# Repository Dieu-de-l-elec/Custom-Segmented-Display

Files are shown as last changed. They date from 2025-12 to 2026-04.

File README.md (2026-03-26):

# Custom Segmented Display

This project is a customizable Segmented display, consisting of a PCB and a top 3d printed diffuser part.
It comes with 32 0603 LEDs arranged in 3 digits, 5-LED light bar and 4 custom indicators. For the top cover, it's mainly a 3d printed part, with tracing paper acting as a diffuser. I'm using double sided adhesive sheets to place the diffusing film on top of the 3d print. The top cover can be attached to the PCB with 4 Phillips head screws. (4 threaded inserts would have been added to the 3d printed part beforehand).

demo here: https://youtu.be/plXIUfEDHeE

banner
RENDER CAD 2
RENDER CAD 2

# Key features:
- **32 LEDs**
- **3 digits** (7 segment digit) including two dots
- 5-LED bar on the bottom left corner
- based on **2 AW9523** ICs: cheap and efficient
- **I²C** communication: up to 2 modules on the same I²C bus
- each LED is driven in **constant current**, with **256 levels of brightness**
- The top diffuser 3d printed part can be swapped with a custom made diffuser, so multiple segmented displays fonts can be achieved. Here is a link of an awesome video made by Pozy, exploring custom Segmented Display fonts: *Segmented Displays* link: https://www.youtube.com/watch?v=RTB5XhjbgZA&t=301s. I designed a top cover taking inspiration from the ***Seamless*** font (4:35)
- Pins accessibles via **Dupont Headers** or **FPC 6P**
- PCB size: 80mm by 25mm
  
# Pinout:

- ***GND***
- ***N.RST*** (negative Reset) Pull LOW to reset the two AW9523 ICs
- ***N.EN*** (negative LED enable) Pull LOW to enable VCC.LED: Only when the AW9523 are well initialized.
- ***SCL***
- ***SDA***
- ***VCC*** 5.0V or 3.3V: 3.3V only possible if the 0603 LEDs used have a forward voltage low enough (if powered with 3.3V, prefer using RED LEDs)

# Software

I made an Arduino code, which while not being the most optimized one, should be sufficient for testing...

# PCB design:

2 Layer PCB designed in EASYEDA (Pro edition)

# Schematic:

SCHEMATIC

# PCB Layout: 

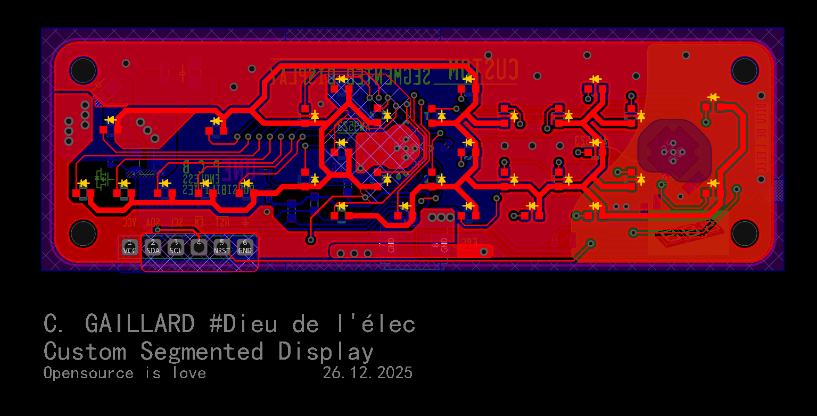
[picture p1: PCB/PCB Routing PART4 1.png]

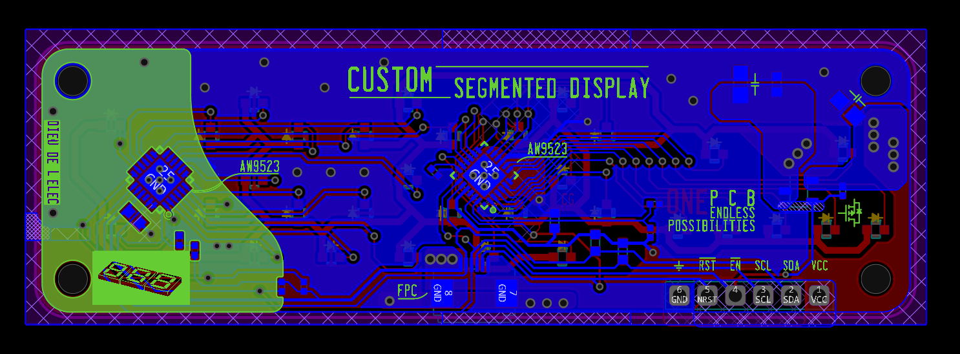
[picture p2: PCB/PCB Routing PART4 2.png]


# CAD (Top cover diffuser):

RENDER CAD 2
RENDER CAD 1

# Renders:
PCB Routing Part3 iso
RENDER 1B
RENDER 1
RENDER 2
RENDER 3
RENDER 4
RENDER 5
RENDER 6
RENDER CAD 1
RENDER CAD 2
RENDER CAD 3
RENDER CAD 4
RENDER CAD 5
RENDER CAD 7
RENDER CAD 6

# Building the display:

Here are the PCB soldered:




## Top diffuser:
The parts are 3d printed in a black filament, so that light cannot pass through, resulting in sharp segments.
The 4 tiles didn't came out perfect, the 3d printed walls almost fused together so the icons aren't really visible, maybe in a V2 I'll increase the groove size.
Other than that, the 3d printed top cover was looking really good, and after sanding down the two top and bottom surfaces, adding the 4 threaded inserts, and placing tracing paper on top with the help of double sided translucent adhesive, the top diffuser was ready to go. Here is the result:












# BOM:

Qty	| Part	| Value | link
--- | --- | --- | ---
3	| 0603 Ceramic Cap	| 100nF | https://www.lcsc.com/product-detail/C66501.html
2	| 0805 Ceramic Cap	| 22µF | https://www.lcsc.com/product-detail/C602037.html
1	| FPC 6P Connector	| FPC-05F-6PH20 | https://www.lcsc.com/product-detail/C2856796.html
1	| Dupont Header 1x6P	| HDR-M_2.54_1x6P | https://www.lcsc.com/product-detail/C37208.html
32 | 0603 LEDs	| Any color | https://www.lcsc.com/product-detail/C965800.html
1	| P-channel Mosfet	| AO3415A | https://www.lcsc.com/product-detail/C133233.html?s_z=n_AO3415A
6	| 0402 Resistor	| 1K | https://www.lcsc.com/product-detail/C2906864.html
2	| 0402 Resistor	| 10K | https://www.lcsc.com/product-detail/C2906861.html
2	| 0603 Resistor	| 4.7K | https://www.lcsc.com/product-detail/C2907034.html
2	| QFN-24 16 channel LED Controller | AW9523BTQR | https://www.lcsc.com/product-detail/C148077.html
1	| Custom PCB | 	
_ | _ | _ | _
_ | _ | _ | _
4	| Threaded inserts	| M2x4x3.5 | https://fr.aliexpress.com/item/1005010298290044.html
4	| Screws	| M2x5 | https://fr.aliexpress.com/item/1005005395957622.html
1	| Custom 3D printed Top Cover Diffuser	| _
(1)	| Double sided adhesive sheet	| (diffusing top layer) | https://fr.aliexpress.com/item/1005005445296074.html
(1)	| Tracing paper sheet	| (diffusing top layer) | https://fr.aliexpress.com/item/1005007419166941.html
(1)	| FPC ribbon cable	8P | .5mm pitch .300mm thick | https://www.lcsc.com/product-detail/C2857689.html

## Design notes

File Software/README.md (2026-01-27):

Here are the Arduino codes for testing the Custom segmented display

The 'Custom_Segmented_Display_demo_code.ino' file is only kept here for archive.

The recommended demo code is now : 'DEMO_Custom_Segmented_Display.ino'

code explanation

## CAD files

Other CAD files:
CAD and RENDERS/CUSTOM SEGMENTED DISPLAY 3D PCB.f3d
CAD and RENDERS/Custom SEGMENTED DISPLAY ASSEMBLY.f3z

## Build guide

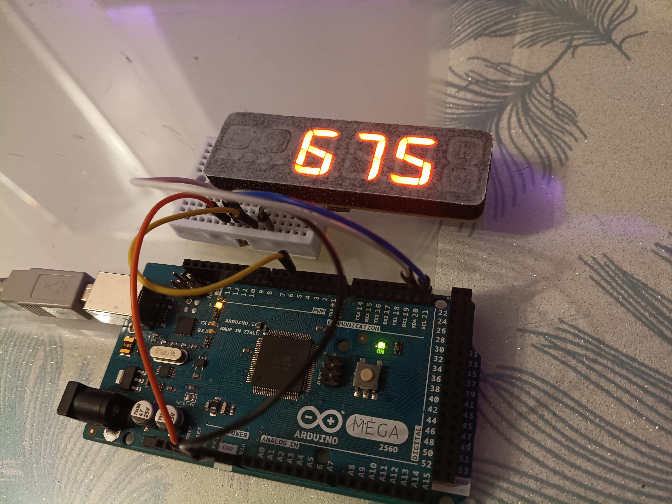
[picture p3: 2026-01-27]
Build Imgs/Build 07.jpg

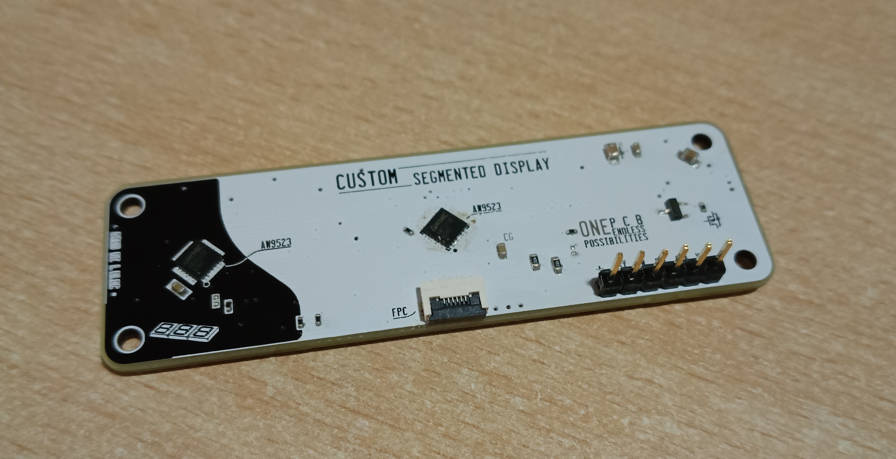
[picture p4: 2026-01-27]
Build Imgs/Build 001.jpg

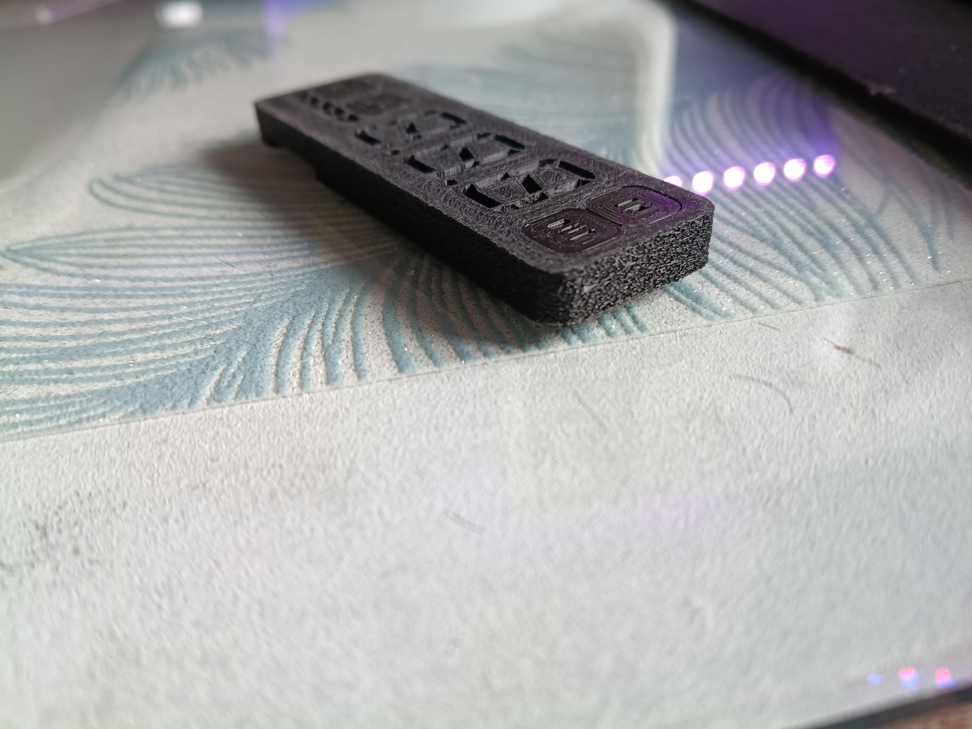
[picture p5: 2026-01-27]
Build Imgs/Build 08.jpg

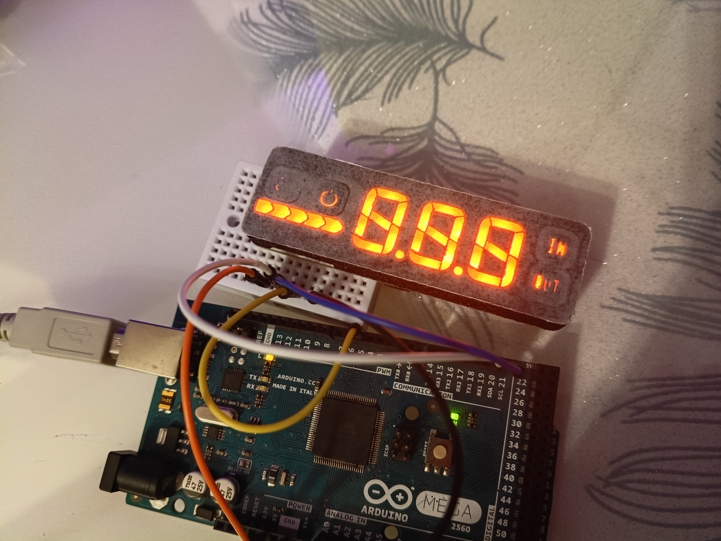
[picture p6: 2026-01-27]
Build Imgs/Build 06.jpg

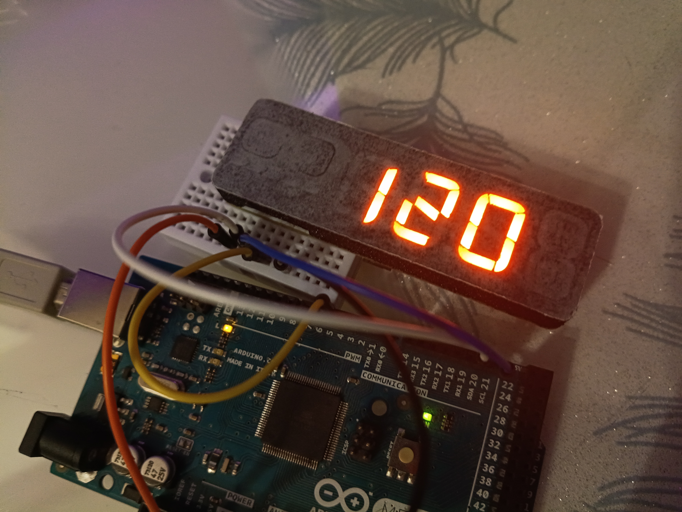
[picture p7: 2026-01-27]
Build Imgs/Build 04.jpg

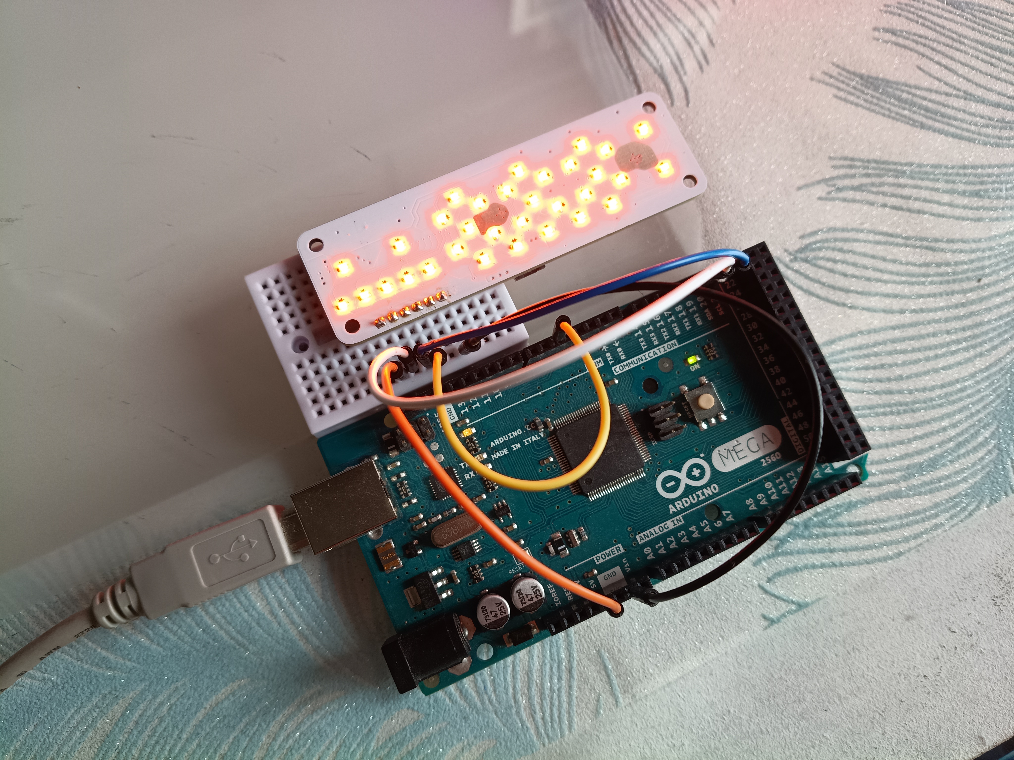
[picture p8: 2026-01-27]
Build Imgs/Build 10.jpg

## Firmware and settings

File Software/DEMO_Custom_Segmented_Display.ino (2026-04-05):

// Custom 7 segment Display Code based on the Adafruit AW9523 library example 
// Newer version, this is far from the most optimized code, but at least it's more efficient than the previous code. It's still good enough for my use cases.

#include "Adafruit_AW9523.h"

Adafruit_AW9523 awA;
Adafruit_AW9523 awB;

int brightness = 80;         // 0 to 255        255 = IMAX, should be 37mA [...]

#define LED_Neg_EN 5 //replace with whatever pin you want
#define Neg_RST 6    // here too

uint8_t pinsMatrixA [4][4] = {
  {0, 1, 2, 3},         //  C_2 [0][0]       C_3 [0][1]    E_3 [0][2]     G_3 [0][3]
  {4, 5, 6, 7},         //  G_2 [1][0]       F_3 [1][1]    B_2 [1][2]     F_2 [1][3]
  {8, 9, 10, 11},       //  ICON4 [2][0]     D_3 [2][1]    DP_2 [2][2]    D_2 [2][3]
  {12, 13, 14, 15}      //  A_2 [3][0]       A_3 [3][1]    B_3 [3][2]     ICON3 [3][3]
};

uint8_t pinsMatrixB [4][4] = {
  {0, 1, 2, 3},         //  LED_BAR_2 [0][0]    LED_BAR_1 [0][1]      ICON1 [0][2]        ICON3 [0][3]
  {4, 5, 6, 7},         //  A_1 [1][0]          F_1 [1][1]            B_1 [1][2]          G_1 [1][3]
  {8, 9, 10, 11},       //  E_1 [2][0]          LED_BAR_5 [2][1]      LED_BAR_4 [2][2]    LED_BAR_3 [2][3]
  {12, 13, 14, 15}      //  C_1 [3][0]          D_1 [3][1]            DP_1 [3][2]         E_2 [3][3]
};

bool stateMatrixA [4][4] = {
  {0, 0, 0, 0},         //  C_2 [0][0]       C_3 [0][1]    E_3 [0][2]     G_3 [0][3]
  {0, 0, 0, 0},         //  G_2 [1][0]       F_3 [1][1]    A_2 [1][2]     F_2 [1][3]
  {0, 0, 0, 0},         //  ICON4 [2][0]    D_3 [2][1]    DP3 [2][2]    D_2 [2][3]
  {0, 0, 0, 0}         //  A_2 [3][0]       A_3 [3][1]    B_3 [3][2]     ICON3 [3][3]
};

bool NstateMatrixA [4][4] = {
  {0, 0, 0, 0},         //  C_2 [0][0]       C_3 [0][1]    E_3 [0][2]     G_3 [0][3]
  {0, 0, 0, 0},         //  G_2 [1][0]       F_3 [1][1]    A_2 [1][2]     F_2 [1][3]
  {0, 0, 0, 0},         //  ICON4 [2][0]    D_3 [2][1]    DP3 [2][2]    D_2 [2][3]
  {0, 0, 0, 0}         //  A_2 [3][0]       A_3 [3][1]    B_3 [3][2]     ICON3 [3][3]
};

bool stateMatrixB [4][4] = {
  {0, 0, 0, 0},         //  LED_BAR_2 [0][0]    LED_BAR_1 [0][1]      ICON1 [0][2]        ICON2 [0][3]
  {0, 0, 0, 0},         //  A_1 [1][0]          F_1 [1][1]            B_1 [1][2]          G_1 [1][3]
  {0, 0, 0, 0},         //  E_1 [2][0]          LED_BAR_5 [2][1]      LED_BAR_4 [2][2]    LED_BAR_3 [2][3]
  {0, 0, 0, 0}         //  C_1 [3][0]          D_1 [3][1]            DP_1 [3][2]         E_2 [3][3]
};

bool NstateMatrixB [4][4] = {
  {0, 0, 0, 0},         //  LED_BAR_2 [0][0]    LED_BAR_1 [0][1]      ICON1 [0][2]        ICON2 [0][3]
  {0, 0, 0, 0},         //  A_1 [1][0]          F_1 [1][1]            B_1 [1][2]          G_1 [1][3]
  {0, 0, 0, 0},         //  E_1 [2][0]          LED_BAR_5 [2][1]      LED_BAR_4 [2][2]    LED_BAR_3 [2][3]
  {0, 0, 0, 0}         //  C_1 [3][0]          D_1 [3][1]            DP_1 [3][2]         E_2 [3][3]
};


void setup() {
  pinMode (LED_Neg_EN, OUTPUT);
  digitalWrite (LED_Neg_EN, HIGH);
  Serial.begin(115200);
  while (!Serial) delay(1);  // wait for serial port to open

  Serial.println("Custom Segmented Display ready to use");

  if (! awA.begin(0x5B)) { // or 0x59
    Serial.println("AW9523-A not found...");
    while (1) delay(10);  // halt forever
  }

  if (! awB.begin(0x58)) { // or 0x5B
    Serial.println("AW9523-B not found...");
    while (1) delay(10);  // halt forever
  }

  Serial.println("Custom Segmented display ready to go!");

  for (int PIN = 0; PIN <= 15; PIN++) {
    awA.pinMode(PIN, AW9523_LED_MODE); // set to constant current drive
    awB.pinMode(PIN, AW9523_LED_MODE); // set to constant current drive
  }
  delay (2000);
  digitalWrite (LED_Neg_EN, LOW);     // Enable VCC.LEDs

}

void loop() {
  clearALL();
  for (int b = 0; b <= 100; b++) {    // two dots gradually lighting up
    brightness = b;
    NstateMatrixB[3][2] = 1;    // DP_1
    NstateMatrixA[2][2] = 1;    // DP_2
    forcedRefreshDisplay();
    delay (100);
  }
  clearALL();
  for (int level = 0; level <= 5; level++) {    // light Bar test
    LightBar (level);
    delay (1000);
  }

  for (int b = 0; b <= 80; b++) {
    brightness = b;
    litALL();
    forcedRefreshDisplay();
    delay (100);
  }
  clearALL();
  NstateMatrixB[0][2] = 1;    // Icon 1
  delay (800);
  refreshDisplay();
  NstateMatrixB[0][3] = 1;    // Icon 2
  delay (800);
  refreshDisplay();
  NstateMatrixA[3][3] = 1;    // Icon 3
  delay (800);
  refreshDisplay();
  NstateMatrixA[2][0] = 1;    // Icon 4
  delay (800);
  refreshDisplay();
  delay (2000);
  clearALL();

  for (int num = 0; num <= 999; num++) {    // counts up to 999
    displayNumber (num);
    delay (150);
  }
  clearALL();
}

void displayDIGIT (int number, int digit) {
  
  bool  A_1 = NstateMatrixB[1][0];
  bool  A_2 = NstateMatrixA[3][0];
  bool  A_3 = NstateMatrixA[3][1];

  bool B_1 = NstateMatrixB[1][2];
  bool B_2 = NstateMatrixA[1][2];
  bool B_3 = NstateMatrixA[3][2];

  bool C_1 = NstateMatrixB[3][0];
  bool C_2 = NstateMatrixA[0][0];
  bool C_3 = NstateMatrixA[0][1];

  bool D_1 = NstateMatrixB[3][1];
  bool D_2 = NstateMatrixA[2][3];
  bool D_3 = NstateMatrixA[2][1];

  bool E_1 = NstateMatrixB[2][0];
  bool E_2 = NstateMatrixB[3][3];
  bool E_3 = NstateMatrixA[0][2];

  bool F_1 = NstateMatrixB[1][1];
  bool F_2 = NstateMatrixA[1][3];
  bool F_3 = NstateMatrixA[1][1];

  bool G_1 = NstateMatrixB[1][3];
  bool G_2 = NstateMatrixA[1][0];
  bool G_3 = NstateMatrixA[0][3];

  bool DP_1 = NstateMatrixB[3][2];
  bool DP_2 = NstateMatrixA[2][2];

  switch (digit) {
    case 1 :
      switch (number) {
        case 0:
          A_1 = 1;
          B_1 = 1;
          C_1 = 1;
          D_1 = 1;
          E_1 = 1;
          F_1 = 1;
          G_1 = 0;
          break;
        case 1:
          A_1 = 0;
          B_1 = 1;
          C_1 = 1;
          D_1 = 0;
          E_1 = 0;
          F_1 = 0;
          G_1 = 0;
          break;
        case 2:
          A_1 = 1;
          B_1 = 1;
          C_1 = 0;
          D_1 = 1;
          E_1 = 1;
          F_1 = 0;
          G_1 = 1;
          break;
        case 3:
          A_1 = 1;
          B_1 = 1;
          C_1 = 1;
          D_1 = 1;
          E_1 = 0;
          F_1 = 0;
          G_1 = 1;
          break;
        case 4:
          A_1 = 0;
          B_1 = 1;
          C_1 = 1;
          D_1 = 0;
          E_1 = 0;
          F_1 = 1;
          G_1 = 1;
          break;
        case 5:
          A_1 = 1;
          B_1 = 0;
          C_1 = 1;
          D_1 = 1;
          E_1 = 0;
          F_1 = 1;
          G_1 = 1;
          break;
        case 6:
          A_1 = 1;
          B_1 = 0;
          C_1 = 1;
          D_1 = 1;
          E_1 = 1;
          F_1 = 1;
          G_1 = 1;
          break;
        case 7:
          A_1 = 1;
          B_1 = 1;
          C_1 = 1;
          D_1 = 0;
          E_1 = 0;
          F_1 = 0;
          G_1 = 0;
          break;
        case 8:
          A_1 = 1;
          B_1 = 1;
          C_1 = 1;
          D_1 = 1;
          E_1 = 1;
          F_1 = 1;
          G_1 = 1;
          break;
        case 9:
          A_1 = 1;
          B_1 = 1;
          C_1 = 1;
          D_1 = 1;
          E_1 = 0;
          F_1 = 1;
          G_1 = 1;
          break;
      }
      break;

    case 2 :
      switch (number) {
        case 0:
          A_2 = 1;
          B_2 = 1;
          C_2 = 1;
          D_2 = 1;
          E_2 = 1;
          F_2 = 1;
          G_2 = 0;
          break;
        case 1:
          A_2 = 0;
          B_2 = 1;
          C_2 = 1;
          D_2 = 0;
          E_2 = 0;
          F_2 = 0;
          G_2 = 0;
          break;
        case 2:
          A_2 = 1;
          B_2 = 1;
          C_2 = 0;
          D_2 = 1;
          E_2 = 1;
          F_2 = 0;
          G_2 = 1;
          break;
        case 3:
          A_2 = 1;
          B_2 = 1;
          C_2 = 1;
          D_2 = 1;
          E_2 = 0;
          F_2 = 0;
          G_2 = 1;
          break;
        case 4:
          A_2 = 0;
          B_2 = 1;
          C_2 = 1;
          D_2 = 0;
          E_2 = 0;
          F_2 = 1;
          G_2 = 1;
          break;
        case 5:
          A_2 = 1;
          B_2 = 0;
          C_2 = 1;
          D_2 = 1;
          E_2 = 0;
          F_2 = 1;
          G_2 = 1;
          break;
        case 6:
          A_2 = 1;
          B_2 = 0;
          C_2 = 1;
          D_2 = 1;
          E_2 = 1;
          F_2 = 1;
          G_2 = 1;
          break;
        case 7:
          A_2 = 1;
          B_2 = 1;
          C_2 = 1;
          D_2 = 0;
          E_2 = 0;
          F_2 = 0;
          G_2 = 0;
          break;
        case 8:
          A_2 = 1;
          B_2 = 1;
          C_2 = 1;
          D_2 = 1;
          E_2 = 1;
          F_2 = 1;
          G_2 = 1;
          break;
        case 9:
          A_2 = 1;
          B_2 = 1;
          C_2 = 1;
          D_2 = 1;
          E_2 = 0;
          F_2 = 1;
          G_2 = 1;
          break;
      }
      break;


    case 3 :
      switch (number) {
        case 0:
          A_3 = 1;
          B_3 = 1;
          C_3 = 1;
          D_3 = 1;
          E_3 = 1;
          F_3 = 1;
          G_3 = 0;
          break;
        case 1:
          A_3 = 0;
          B_3 = 1;
          C_3 = 1;
          D_3 = 0;
          E_3 = 0;
          F_3 = 0;
          G_3 = 0;
          break;
        case 2:
          A_3 = 1;
          B_3 = 1;
          C_3 = 0;
          D_3 = 1;
          E_3 = 1;
          F_3 = 0;
          G_3 = 1;
          break;
        case 3:
          A_3 = 1;
          B_3 = 1;
          C_3 = 1;
          D_3 = 1;
          E_3 = 0;
          F_3 = 0;
          G_3 = 1;
          break;
        case 4:
          A_3 = 0;
          B_3 = 1;
          C_3 = 1;
          D_3 = 0;
          E_3 = 0;
          F_3 = 1;
          G_3 = 1;
          break;
        case 5:
          A_3 = 1;
          B_3 = 0;
          C_3 = 1;
          D_3 = 1;
          E_3 = 0;
          F_3 = 1;
          G_3 = 1;
          break;
        case 6:
          A_3 = 1;
          B_3 = 0;
          C_3 = 1;
          D_3 = 1;
          E_3 = 1;
          F_3 = 1;
          G_3 = 1;
          break;
        case 7:
          A_3 = 1;
          B_3 = 1;
          C_3 = 1;
          D_3 = 0;
          E_3 = 0;
          F_3 = 0;
          G_3 = 0;
          break;
        case 8:
          A_3 = 1;
          B_3 = 1;
          C_3 = 1;
          D_3 = 1;
          E_3 = 1;
          F_3 = 1;
          G_3 = 1;
          break;
        case 9:
          A_3 = 1;
          B_3 = 1;
          C_3 = 1;
          D_3 = 1;
          E_3 = 0;
          F_3 = 1;
          G_3 = 1;
          break;
      }
      break;
  }

  NstateMatrixB[1][0] = A_1;
  NstateMatrixA[3][0] = A_2;
  NstateMatrixA[3][1] = A_3;

  NstateMatrixB[1][2] = B_1;
  NstateMatrixA[1][2] = B_2;
  NstateMatrixA[3][2] = B_3;

  NstateMatrixB[3][0] = C_1;
  NstateMatrixA[0][0] = C_2;
  NstateMatrixA[0][1] = C_3;

  NstateMatrixB[3][1] = D_1;
  NstateMatrixA[2][3] = D_2;
  NstateMatrixA[2][1] = D_3;

  NstateMatrixB[2][0] = E_1;
  NstateMatrixB[3][3] = E_2;
  NstateMatrixA[0][2] = E_3;

  NstateMatrixB[1][1] = F_1;
  NstateMatrixA[1][3] = F_2;
  NstateMatrixA[1][1] = F_3;

  NstateMatrixB[1][3] = G_1;
  NstateMatrixA[1][0] = G_2;
  NstateMatrixA[0][3] = G_3;

  NstateMatrixB[3][2] = DP_1;
  NstateMatrixA[2][2] = DP_2;

  refreshDisplay();

}

void clearNumbers() {

  NstateMatrixB[1][0] = 0;
  NstateMatrixB[1][1] = 0;
  NstateMatrixB[1][2] = 0;
  NstateMatrixB[1][3] = 0;
  NstateMatrixB[2][0] = 0;
  NstateMatrixB[3][0] = 0;
  NstateMatrixB[3][1] = 0;
  NstateMatrixB[3][2] = 0;
  NstateMatrixB[3][3] = 0;

  NstateMatrixA[0][0] = 0;
  NstateMatrixA[0][1] = 0;
  NstateMatrixA[0][2] = 0;
  NstateMatrixA[0][3] = 0;
  NstateMatrixA[1][0] = 0;
  NstateMatrixA[1][1] = 0;
  NstateMatrixA[1][2] = 0;
  NstateMatrixA[1][3] = 0;
  NstateMatrixA[2][1] = 0;
  NstateMatrixA[2][2] = 0;
  NstateMatrixA[2][3] = 0;
  NstateMatrixA[3][0] = 0;
  NstateMatrixA[3][1] = 0;
  NstateMatrixA[3][2] = 0;

  refreshDisplay();
}

void clearALL() {

  for (int l = 0; l <= 3; l++) {
    for (int c = 0; c <= 3; c++) {
      NstateMatrixA[l][c] = 0;
      NstateMatrixB[l][c] = 0;
    }
  }
  refreshDisplay();
}

void refreshDisplay() {
  for (int l = 0; l <= 3; l++) {
    for (int c = 0; c <= 3; c++) {
      if (stateMatrixA[l][c] != NstateMatrixA[l][c]) {
        awA.analogWrite (pinsMatrixA [l][c], brightness * NstateMatrixA[l][c]); // br * 0 = 0 or br * 1 = br
      }
      stateMatrixA[l][c] = NstateMatrixA[l][c];
      if (stateMatrixB[l][c] != NstateMatrixB[l][c]) {
        awB.analogWrite (pinsMatrixB [l][c], brightness * NstateMatrixB[l][c]);
      }
      stateMatrixB[l][c] = NstateMatrixB[l][c];
    }
  }
}

void forcedRefreshDisplay() {
  for (int l = 0; l <= 3; l++) {
    for (int c = 0; c <= 3; c++) {
      awA.analogWrite (pinsMatrixA [l][c], brightness * NstateMatrixA[l][c]); // br * 0 = 0 or br * 1 = br
      stateMatrixA[l][c] = NstateMatrixA[l][c];
      awB.analogWrite (pinsMatrixB [l][c], brightness * NstateMatrixB[l][c]);
      stateMatrixB[l][c] = NstateMatrixB[l][c];
    }
  }
}
void litALL() {
  for (int l = 0; l <= 3; l++) {
    for (int c = 0; c <= 3; c++) {
      NstateMatrixA[l][c] = 1;
      NstateMatrixB[l][c] = 1;
    }
  }
  refreshDisplay();
}

void displayNumber (int value) {          // Displays value from 0 to 999

  value = constrain(value, 0, 999);
  int firstDigit  = value / 100;
  int secondDigit = (value / 10) % 10;
  int thirdDigit  = value % 10;

  //clearNumbers();

  displayDIGIT (firstDigit, 1);
  displayDIGIT (secondDigit, 2);
  displayDIGIT (thirdDigit, 3);

}

void LightBar (int value) {

  switch (value) {
    case 0:
      NstateMatrixB[0][1] = 0; //LED BAR 1
      NstateMatrixB[0][0] = 0; //LED BAR 2
      NstateMatrixB[2][3] = 0; //LED BAR 3
      NstateMatrixB[2][2] = 0; //LED BAR 4
      NstateMatrixB[2][1] = 0; //LED BAR 5
      break;
    case 1:
      NstateMatrixB[0][1] = 1; //LED BAR 1
      NstateMatrixB[0][0] = 0; //LED BAR 2
      NstateMatrixB[2][3] = 0; //LED BAR 3
      NstateMatrixB[2][2] = 0; //LED BAR 4
      NstateMatrixB[2][1] = 0; //LED BAR 5
      break;
    case 2:
      NstateMatrixB[0][1] = 1; //LED BAR 1
      NstateMatrixB[0][0] = 1; //LED BAR 2
      NstateMatrixB[2][3] = 0; //LED BAR 3
      NstateMatrixB[2][2] = 0; //LED BAR 4
      NstateMatrixB[2][1] = 0; //LED BAR 5
      break;
    case 3:
      NstateMatrixB[0][1] = 1; //LED BAR 1
      NstateMatrixB[0][0] = 1; //LED BAR 2
      NstateMatrixB[2][3] = 1; //LED BAR 3
      NstateMatrixB[2][2] = 0; //LED BAR 4
      NstateMatrixB[2][1] = 0; //LED BAR 5
      break;
    case 4:
      NstateMatrixB[0][1] = 1; //LED BAR 1
      NstateMatrixB[0][0] = 1; //LED BAR 2
      NstateMatrixB[2][3] = 1; //LED BAR 3
      NstateMatrixB[2][2] = 1; //LED BAR 4
      NstateMatrixB[2][1] = 0; //LED BAR 5
      break;
    case 5:
      NstateMatrixB[0][1] = 1; //LED BAR 1
      NstateMatrixB[0][0] = 1; //LED BAR 2
      NstateMatrixB[2][3] = 1; //LED BAR 3
      NstateMatrixB[2][2] = 1; //LED BAR 4
      NstateMatrixB[2][1] = 1; //LED BAR 5
      break;
  }

  refreshDisplay();
}

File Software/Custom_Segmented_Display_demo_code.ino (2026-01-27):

// Custom 7 segment Display Code based on the Adafruit AW9523 library example
// This is far from the most optimized code, but it should be enough for testing.




// First code, it works but not efficient. just here for archive...







#include "Adafruit_AW9523.h"

Adafruit_AW9523 awA;
Adafruit_AW9523 awB;

int brightness = 80;         // 0 to 255        255 = IMAX, should be 37mA [...]

#define LED_Neg_EN 20 //replace with whatever pin you want
#define Neg_RST 21    // here too

uint8_t A_1 = 4;   //P0_4 B
uint8_t B_1 = 6;   //P0_6 B
uint8_t C_1 = 12;  //P1_4 B
uint8_t D_1 = 13;  //P1_5 B
uint8_t E_1 = 8;   //P1_0 B
uint8_t F_1 = 5;   //P0_5 B
uint8_t G_1 = 7;   //P0_7 B
uint8_t DP_1 = 14; //P1_6 B

uint8_t A_2 = 12;  //P1_4 A
uint8_t B_2 = 6;   //P0_6 A
uint8_t C_2 = 0;   //P0_0 A
uint8_t D_2 = 10;  //P1_2 A
uint8_t E_2 = 15;  //P1_7 B
uint8_t F_2 = 7;   //P0_7 A
uint8_t G_2 = 4;   //P0_4 A
uint8_t DP_2 = 11; //P1_3 A

uint8_t A_3 = 13;  //P1_5 A
uint8_t B_3 = 14;  //P1_6 A
uint8_t C_3 = 1;   //P0_1 A
uint8_t D_3 = 9;   //P1_1 A
uint8_t E_3 = 2;   //P0_2 A
uint8_t F_3 = 5;   //P0_5 A
uint8_t G_3 = 3;   //P0_3 A

uint8_t ICON1 = 2;    //P0_2 B
uint8_t ICON2 = 3;    //P0_3 B
uint8_t ICON3 = 15;   //P1_7 A
uint8_t ICON4 = 8;    //P1_0 A

uint8_t LED_BAR_1 = 1;   //P0_1 B
uint8_t LED_BAR_2 = 0;   //P0_0 B
uint8_t LED_BAR_3 = 11;  //P1_3 B
uint8_t LED_BAR_4 = 10;  //P1_2 B
uint8_t LED_BAR_5 = 9;   //P1_1 B


void setup() {
  pinMode (LED_Neg_EN, OUTPUT);
  digitalWrite (LED_Neg_EN, HIGH);
  Serial.begin(115200);
  while (!Serial) delay(1);  // wait for serial port to open

  Serial.println("Custom Segmented Display ready to use");

  if (! awA.begin(0x58)) { // or 0x59
    Serial.println("AW9523-A not found...");
    while (1) delay(10);  // halt forever
  }

  if (! awB.begin(0x5A)) { // or 0x5B
    Serial.println("AW9523-B not found...");
    while (1) delay(10);  // halt forever
  }

  Serial.println("Custom Segmented display ready to go!");

  for (int PIN = 0; PIN <= 15; PIN++) {
    awA.pinMode(PIN, AW9523_LED_MODE); // set to constant current drive
    awB.pinMode(PIN, AW9523_LED_MODE); // set to constant current drive
  }
  delay (500);
  digitalWrite (LED_Neg_EN, LOW);     // Enable VCC.LEDs

}

void loop() {
  clearALL();
  for (int br = 0; br <= brightness; br++) {    // two dots gradually lighting up
    awB.analogWrite (DP_1, br);
    awB.analogWrite (DP_2, br);
    delay (10);
  }
  clearALL();
  for (int level = 0; level <= 5; level++) {    // light Bar test
    LightBar (level);
    delay (1000);
  }
  awB.analogWrite (ICON1, brightness);    // Icons
  delay (200);
  awB.analogWrite (ICON2, brightness);
  delay (200);
  awA.analogWrite (ICON3, brightness);
  delay (200);
  awA.analogWrite (ICON4, brightness);
  delay (2000);
  clearALL();
  for (int num = 0; num <= 999; num++) {    // counts up to 999
    displayNumber (num);
    delay (250);
  }

  digitalWrite (LED_Neg_EN, HIGH);


}

void displayDIGIT (int number, int digit) {
  switch (digit) {
    case 1 :
      switch (number) {
        case 0:
          awB.analogWrite (A_1, brightness);
          awB.analogWrite (B_1, brightness);
          awB.analogWrite (C_1, brightness);
          awB.analogWrite (D_1, brightness);
          awB.analogWrite (E_1, brightness);
          awB.analogWrite (F_1, brightness);
          awB.analogWrite (G_1, 0);
          break;
        case 1:
          awB.analogWrite (A_1, 0);
          awB.analogWrite (B_1, brightness);
          awB.analogWrite (C_1, brightness);
          awB.analogWrite (D_1, 0);
          awB.analogWrite (E_1, 0);
          awB.analogWrite (F_1, 0);
          awB.analogWrite (G_1, 0);
          break;
        case 2:
          awB.analogWrite (A_1, brightness);
          awB.analogWrite (B_1, brightness);
          awB.analogWrite (C_1, 0);
          awB.analogWrite (D_1, brightness);
          awB.analogWrite (E_1, brightness);
          awB.analogWrite (F_1, 0);
          awB.analogWrite (G_1, brightness);
          break;
        case 3:
          awB.analogWrite (A_1, brightness);
          awB.analogWrite (B_1, brightness);
          awB.analogWrite (C_1, brightness);
          awB.analogWrite (D_1, brightness);
          awB.analogWrite (E_1, 0);
          awB.analogWrite (F_1, 0);
          awB.analogWrite (G_1, brightness);
          break;
        case 4:
          awB.analogWrite (A_1, 0);
          awB.analogWrite (B_1, brightness);
          awB.analogWrite (C_1, brightness);
          awB.analogWrite (D_1, 0);
          awB.analogWrite (E_1, 0);
          awB.analogWrite (F_1, brightness);
          awB.analogWrite (G_1, brightness);
          break;
        case 5:
          awB.analogWrite (A_1, brightness);
          awB.analogWrite (B_1, 0);
          awB.analogWrite (C_1, brightness);
          awB.analogWrite (D_1, brightness);
          awB.analogWrite (E_1, 0);
          awB.analogWrite (F_1, brightness);
          awB.analogWrite (G_1, brightness);
          break;
        case 6:
          awB.analogWrite (A_1, brightness);
          awB.analogWrite (B_1, 0);
          awB.analogWrite (C_1, brightness);
          awB.analogWrite (D_1, brightness);
          awB.analogWrite (E_1, brightness);
          awB.analogWrite (F_1, brightness);
          awB.analogWrite (G_1, brightness);
          break;
        case 7:
          awB.analogWrite (A_1, brightness);
          awB.analogWrite (B_1, brightness);
          awB.analogWrite (C_1, brightness);
          awB.analogWrite (D_1, 0);
          awB.analogWrite (E_1, 0);
          awB.analogWrite (F_1, 0);
          awB.analogWrite (G_1, 0);
          break;
        case 8:
          awB.analogWrite (A_1, brightness);
          awB.analogWrite (B_1, brightness);
          awB.analogWrite (C_1, brightness);
          awB.analogWrite (D_1, brightness);
          awB.analogWrite (E_1, brightness);
          awB.analogWrite (F_1, brightness);
          awB.analogWrite (G_1, brightness);
          break;
        case 9:
          awB.analogWrite (A_1, brightness);
          awB.analogWrite (B_1, brightness);
          awB.analogWrite (C_1, brightness);
          awB.analogWrite (D_1, brightness);
          awB.analogWrite (E_1, 0);
          awB.analogWrite (F_1, brightness);
          awB.analogWrite (G_1, brightness);
          break;
      }
      break;
    case 2 :
      switch (number) {
        case 0:
          awA.analogWrite (A_2, brightness);
          awA.analogWrite (B_2, brightness);
          awA.analogWrite (C_2, brightness);
          awA.analogWrite (D_2, brightness);
          awB.analogWrite (E_2, brightness);
          awA.analogWrite (F_2, brightness);
          awA.analogWrite (G_2, 0);
          break;
        case 1:
          awA.analogWrite (A_2, 0);
          awA.analogWrite (B_2, brightness);
          awA.analogWrite (C_2, brightness);
          awA.analogWrite (D_2, 0);
          awB.analogWrite (E_2, 0);
          awA.analogWrite (F_2, 0);
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
